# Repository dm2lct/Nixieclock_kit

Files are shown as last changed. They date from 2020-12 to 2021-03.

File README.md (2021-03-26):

Better version of my nixie clock. 
=====

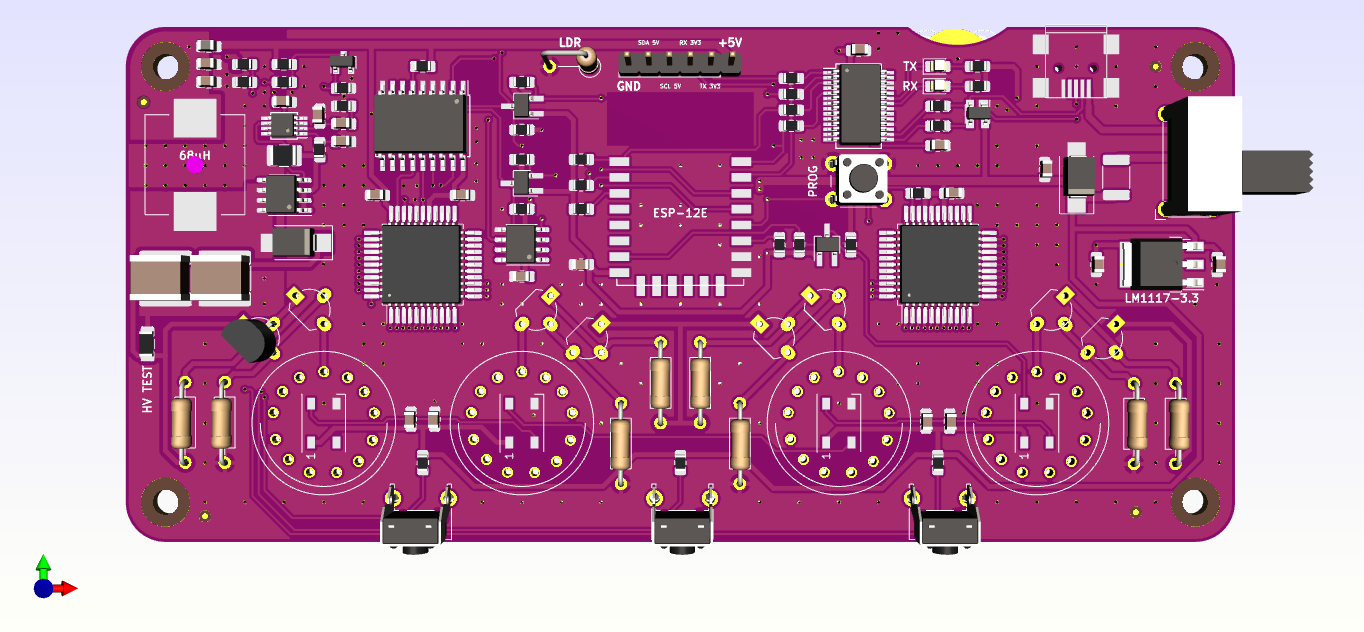
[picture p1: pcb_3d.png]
PCB 3D view Title


Feel free to build your own nixie clock from it.

The firmware can be found at https://codeberg.org/paul/nixie_clock

The documentation and assembly instructions are on https://wiki.turmlabor.de/index.php?title=Nixie_Uhr_Bausatz_2.1 (currently only in german, sorry!)

Features:
  - IN14 nixie tubes but you can adapt many other nixie tubes, but some of them would not fit nicely in the board
  - ESP12e controller so you can make IoT with it and build your own botnet for world domination, if you have enough clocks.
    But mainly the wifi is used to get the time from a ntp-server and for controlling the clock with MQTT
  - DS3231 RTC for everyone who does not like IoT and does also not want to be enslaved from AI
  - WS2812B under each nixie tube to make them look more fancy
  - runs from a simple USB charger, although it uses a mini-usb B socket, which is better to solder, so you need a mini-usb cable
  - you can program the controller with your Arduino IDE over USB
  - optimized nixie power supply. Now the entire clock ownly draws about 450mA from the power supply
  - cleaned up the schematic a little: Simpler protection circuit

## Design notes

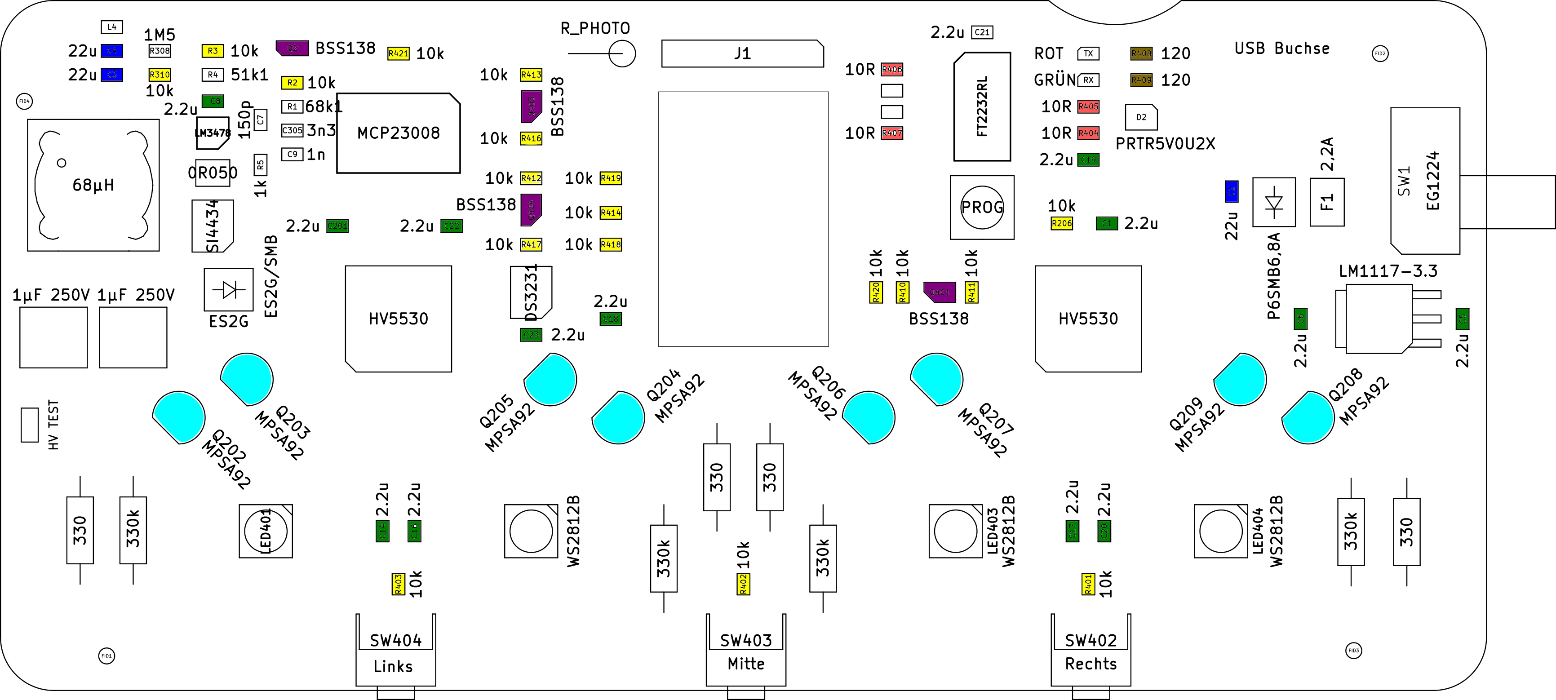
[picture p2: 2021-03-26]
Gerber/Nixie_proj-F.Fab.svg.png

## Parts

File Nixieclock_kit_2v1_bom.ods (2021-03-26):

BOM
Item | Qty | Reference(s) | Value | Reichelt | manf#
1 | 1 | 68uH1 | INDUCTOR | WUE 7447709680 | 7447709680
2 | 1 | BT401 | Battery_Cell |  | BAT-HLD-012-SMT
3 | 14 | C1, C5, C6, C8, C14, C16, C17, C18, C19, C20, C21, C22, C23, C201 | 2.2u | KEM X5R0805 2,2U | C0805C225K8PACTU
4 | 3 | C2, C3, C4 | 22u | X5R-G0805 22/6 | GRM21BR60J226ME39L
5 | 1 | C7 | 150p | KEM C0G0805 150P | C0805C151J5GACTU
6 | 1 | C9 | 1n | KEM C0G0805 150P | C0805C151J5GACTU
7 | 2 | C12, C13 | 1u |  | 2225PC105MAT1A
8 | 1 | C305 | 3n3 | KEM X7R0805 3,3N | C0805C151J5GACTU
9 | 1 | D1 | P6SMB6,8A | P6SMB 6,8A SMD | P6SMB6,8A
10 | 1 | D2 | PRTR5V0U2X |  | PRTR5V0U2X,215
11 | 1 | D304 | ES2G/SMB | ES 2G SMD | ES2G-E3/52T
12 | 1 | D401 | TX | SMD-LED 0805 RT | KP-2012ID
13 | 1 | D402 | RX | SMD-LED 0805 GN | KP-2012SGD
14 | 1 | F1 | 2,2A | LITT MINISMDC110 | MINISMDC110F/24-2
15 | 4 | FID1, FID2, FID3, FID4 | Fiducial | n.b. | n.b.
16 | 4 | H1, H2, H3, H4 | MountingHole | n.b. | n.b.
17 | 1 | J1 | Conn_01x06_Male | n.b. | n.b.
18 | 1 | L4 | Ferrite_Bead | BLM21PG 331 | BLM21PG331 SN1D
19 | 4 | LED401, LED402, LED403, LED404 | WS2812B
20 | 1 | NT1 | Net-Tie_2 | n.b. | n.b.
21 | 1 | P301 | USB_OTG | USB BWM SMD | USB BWM SMD
22 | 1 | Q1 | SI4434 | SI4434DY-GE3 | SI4434DY-T1-GE3
23 | 1 | Q2 | BSS138 | BSS 138 SMD | BSS 138 SMD
24 | 8 | Q202, Q203, Q204, Q205, Q206, Q207, Q208, Q209 | MPSA92 | MPSA 92 | MPSA92
25 | 3 | Q401, Q403, Q404 | BSS138 | BSS 138 SMD | BSS 138 SMD
26 | 1 | R1 | 68k1 | RND 0805 1 68K | RND1550805S8F6802T5E
27 | 18 | R2, R3, R206, R310, R401, R402, R403, R410, R411, R412, R413, R414, R416, R417, R418, R419, R420, R421 | 10k | RND 0805 1 10K | RND1550805S8F1002T5E
28 | 1 | R4 | 51k1 | RND 0805 1 51K | RND1550805S8F5102T5E
29 | 1 | R5 | 1k | RND 0805 1 51K | RND1550805S8F5102T5E
30 | 4 | R201, R203, R205, R208 | 330k | VI MBB02070C3303 | MBB02070C3303FCT00
31 | 4 | R202, R204, R207, R209 | 330 | VI MBB02070C3300 | MBB02070C3300FCT00
32 | 1 | R308 | 1M5 | SMD-0805 1,50M | RC0805FR-071M5L
33 | 4 | R404, R405, R406, R407 | 10R | RND 0805 1 10 | RND1550805S8F100JT5E
34 | 2 | R408, R409 | 120 | RND 0805 1 120 | RND1550805S8F1200T5E
35 | 1 | R415 | R_PHOTO | n.b. | n.b.
36 | 1 | RSENSE301 | 0R050 | PAN ERJ8CWFR050 | ERJ-L14KF50MU
37 | 1 | SW1 | EG1224 |  | EG1224
38 | 1 | SW401 | SW_Push | RND 210-00192 | RND 210-00192
39 | 1 | SW402 | Rechts | RND 210-00258 | RND 210-00258
40 | 1 | SW403 | Mitte | RND 210-00258 | RND 210-00258
41 | 1 | SW404 | Links | RND 210-00258 | RND 210-00258
42 | 4 | TBE201, TBE202, TBE203, TBE204 | IN14
43 | 1 | U1 | DS3231MZ |  | DS3231MZ+
44 | 1 | U2 | LM1117-3.3 | LM 1117 IDT-3.3 | LM1117IDT-3.3/NOPB
45 | 1 | U3 | LM3478 | LM 3478 MM | LM3478MM/NOPB
46 | 2 | U201, U202 | HV5530 bzw HV5522 |  | HV5522PG-G
47 | 1 | U401 | ESP-12E | DEBO ESP8266-12F | ESP-12S
48 | 1 | U402 | FT232RL | FT 232 RL | FT232RL-REEL
49 | 1 | U403 | MCP23008 |  | MCP23008-E/SO
50 | 2 | W401, W402 | TEST_2P | n.b. | n.b.

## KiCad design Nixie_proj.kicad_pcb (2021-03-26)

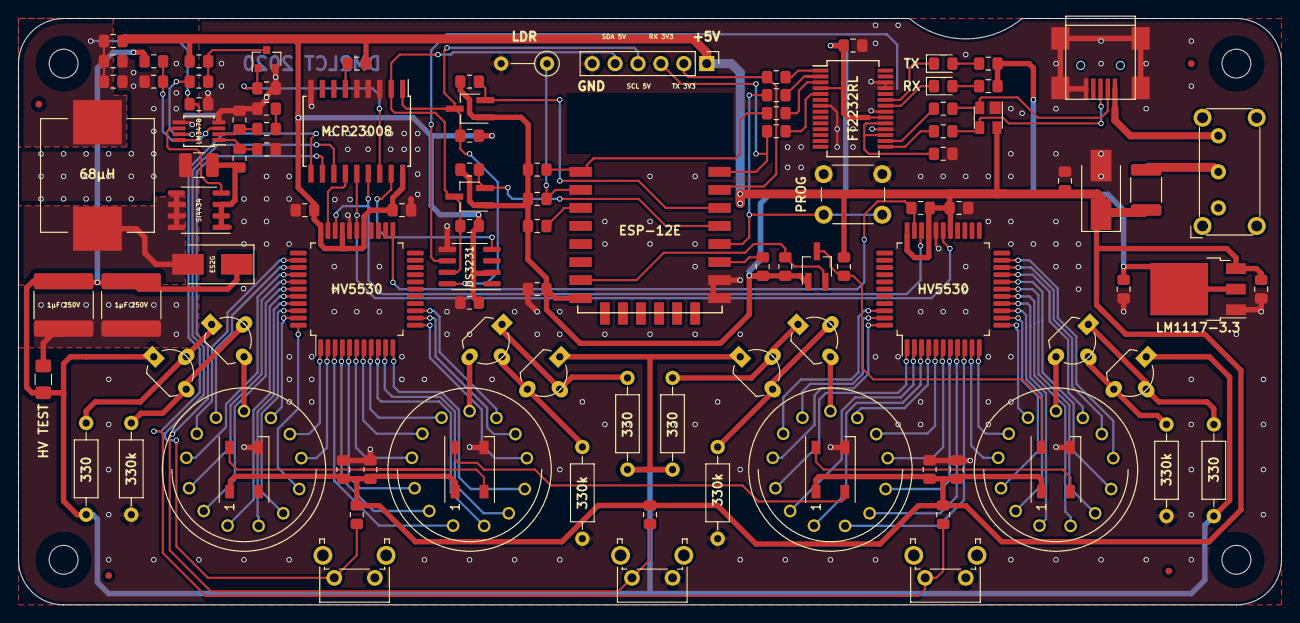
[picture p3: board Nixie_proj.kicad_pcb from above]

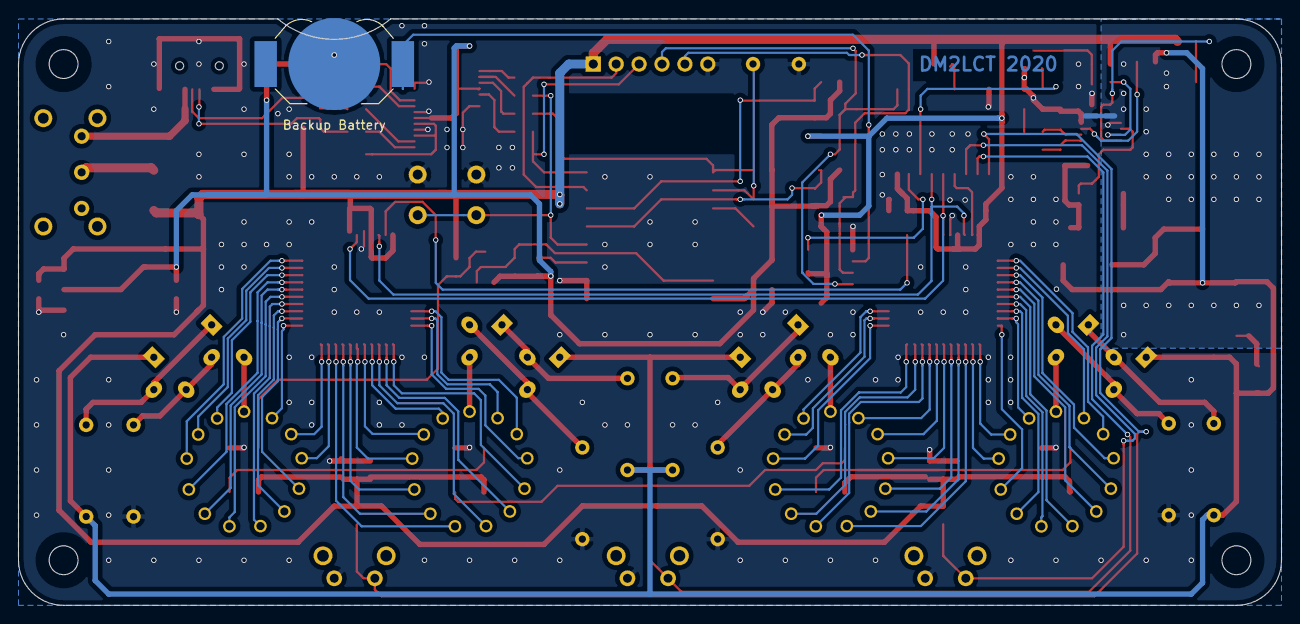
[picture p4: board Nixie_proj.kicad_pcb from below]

Board: 2 copper layers, 140.0 x 65.0 mm, 117 parts (2 on the bottom side), 117 nets.

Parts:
1µF 250V, 1µF 250V#2: 1u; C_2225_5664Metric_Pad1.80x6.60mm_HandSolder
68µH: INDUCTOR; L_Wuerth_WE-PD-Typ-LS_Handsoldering
330, 330#2, 330#3, 330#4: 330; R_Axial_DIN0207_L6.3mm_D2.5mm_P10.16mm_Horizontal
330k, 330k#2, 330k#3, 330k#4: 330k; R_Axial_DIN0207_L6.3mm_D2.5mm_P10.16mm_Horizontal
Backup Battery: Battery_Cell; BatteryHolder_LINX_BAT-HLD-012-SMT
C1, C5, C6, C8, C14, C16, C17, C18, C19, C20, C21, C22, C23, C201: 2.2u; C_0805_2012Metric_Pad1.15x1.40mm_HandSolder
C2, C3, C4: 22u; C_0805_2012Metric_Pad1.15x1.40mm_HandSolder
C7: 150p; C_0805_2012Metric_Pad1.15x1.40mm_HandSolder
C9: 1n; C_0805_2012Metric_Pad1.15x1.40mm_HandSolder
C305: 3n3; C_0805_2012Metric_Pad1.15x1.40mm_HandSolder
D1: P6SMB6,8A; D_SMB_Handsoldering
D2: PRTR5V0U2X; SOT-143
DS3231: DS3231MZ; SOIC-8_3.9x4.9mm_P1.27mm
ES2G: ES2G/SMB; D_SMB_Handsoldering
ESP-12E: ESP-12E; ESP-12E_SMD
F1: 2,2A; Fuse_1812_4532Metric_Pad1.30x3.40mm_HandSolder
FID1, FID2, FID3, FID4: Fiducial; Fiducial_0.75mm_Mask1.5mm
FT2232RL: FT232RL; SSOP-28_5.3x10.2mm_P0.65mm
H1, H2, H3: MountingHole; MountingHole_3.2mm_M3_DIN965
H4: eMountingHole; MountingHole_3.2mm_M3_DIN965
HV5530, HV5530#2: HV5530; MQFP-44_10x10mm_P0.8mm
HV TEST: TEST; R_1206_3216Metric_Pad1.42x1.75mm_HandSolder
J1: Conn_01x06_Male; PinHeader_1x06_P2.54mm_Vertical
L4: Ferrite_Bead; L_0805_2012Metric_Pad1.15x1.40mm_HandSolder
LDR: R_PHOTO; R_Axial_DIN0207_L6.3mm_D2.5mm_P5.08mm_Vertical
LED401, LED402, LED403, LED404: WS2812B; LED_WS2812B_PLCC4_5.0x5.0mm_P3.2mm
LM1117-3.3: LM1117-3.3; TO-252-3_TabPin2
LM3478: LM3478; MSOP-8_3x3mm_P0.65mm
MCP23008: MCP23008; SOIC-18W_7.5x11.6mm_P1.27mm
NT1: Net-Tie_2; NetTie-2_SMD_Pad0.5mm
P301: USB Buchse; USB_Mini-B
PROG: SW_Push; SW_PUSH_6mm_H4.3mm
Q2: BSS138; SOT-23
Q202, Q203, Q204, Q205, Q206, Q207, Q208, Q209: MPSA92; TO-92_Molded_Wide_Oval
Q401, Q403, Q404: BSS138; SOT-23W_Handsoldering
R1: 68k1; R_0805_2012Metric_Pad1.15x1.40mm_HandSolder
R2, R3, R206, R310, R401, R402, R403, R410, R411, R412, R413, R414, R416, R417, R418, R419, R420, R421: 10k; R_0805_2012Metric_Pad1.15x1.40mm_HandSolder
R4: 51k1; R_0805_2012Metric_Pad1.15x1.40mm_HandSolder
R5: 1k; R_0805_2012Metric_Pad1.15x1.40mm_HandSolder
R308: 1M5; R_0805_2012Metric_Pad1.15x1.40mm_HandSolder
R404, R405, R406, R407: 10R; R_0805_2012Metric_Pad1.15x1.40mm_HandSolder
R408, R409: 120; R_0805_2012Metric_Pad1.15x1.40mm_HandSolder
RSENSE301: 0R050; R_1210_3225Metric_Pad1.42x2.65mm_HandSolder
RX: GRÜN; LED_0805_2012Metric_Pad1.15x1.40mm_HandSolder
SI4434: SI4434; SOIC-8_3.9x4.9mm_P1.27mm
SW1: EG1224; SW_E-Switch_EG1224_SPDT_Angled
SW402: Rechts; SW_Tactile_SPST_Angled_PTS645Vx39-2LFS
SW403: Mitte; SW_Tactile_SPST_Angled_PTS645Vx39-2LFS
SW404: Links; SW_Tactile_SPST_Angled_PTS645Vx39-2LFS
TBE201, TBE202, TBE203, TBE204: IN14; IN-14-mod
TX: ROT; LED_0805_2012Metric_Pad1.15x1.40mm_HandSolder
W401, W402: TEST_2P; R_0805_2012Metric_Pad1.15x1.40mm_HandSolder

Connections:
+3V3: C6.1, C18.1, C21.2, ESP-12E.8, FT2232RL.4, FT2232RL.20, LM1117-3.3.2, Q401.1, Q403.1, Q404.1, R408.1, R409.1, R410.1, R412.1, R413.1, R414.1, R418.1, R419.1, R420.1
+5V: C1.1, C2.1, C5.1, C14.1, C16.1, C17.1, C20.1, C22.1, C23.2, C201.1, D1.1, D2.4, DS3231.2, F1.1, HV5530.27, HV5530.30, HV5530.33, HV5530#2.27, HV5530#2.30, HV5530#2.33, J1.1, L4.2, LED401.1, LED402.1, LED403.1, LED404.1, LM1117-3.3.3, MCP23008.18, R3.2, R206.1, R401.2, R402.2, R403.2, R411.1, R416.1, R417.1, R421.1
/Microcontroller and clock/BTN1: MCP23008.10, R401.1, SW402.2
/Microcontroller and clock/BTN2: MCP23008.11, R402.1, SW403.2
/Microcontroller and clock/BTN3: MCP23008.12, R403.1, SW404.2
/Microcontroller and clock/HVCLOCK: HV5530.28, HV5530#2.28, MCP23008.14
/Microcontroller and clock/HVDATA: HV5530.32, MCP23008.13
/Microcontroller and clock/HVSTROBE: HV5530.31, HV5530#2.31, MCP23008.15
/Microcontroller and clock/HV_SHDN: MCP23008.16, Q2.1, R2.2
/Microcontroller and clock/RX: ESP-12E.16, J1.3, R407.1
/Microcontroller and clock/SCL_3V3: ESP-12E.14, Q403.2, R413.2
/Microcontroller and clock/SCL_5V: DS3231.8, J1.4, MCP23008.1, Q403.3, R416.2
/Microcontroller and clock/SDA_3V3: ESP-12E.13, Q404.2, R412.2
/Microcontroller and clock/SDA_5V: DS3231.7, J1.5, MCP23008.2, Q404.3, R417.2
/Microcontroller and clock/TX: ESP-12E.15, J1.2, R406.1
/Microcontroller and clock/USBD+: D2.3, P301.3, R404.2
/Microcontroller and clock/USBD-: D2.2, P301.2, R405.2
/Power Supply/Boost_Drain: 68µH.2, ES2G.2, SI4434.5, SI4434.6, SI4434.7, SI4434.8
/Power Supply/Boost_ZK: 68µH.1, C3.1, C4.1, C8.2, L4.1, LM3478.8
/Power Supply/FB: LM3478.3, R308.2, R310.1
/Power Supply/Isen: C9.2, LM3478.1, R5.2
/Power Supply/PWRGND: 1µF 250V.2, 1µF 250V#2.2, C3.2, C4.2, HV TEST.2, LM3478.5, NT1.1, R310.2, RSENSE301.2
/Tubes with drivers/A0: HV5530.2, TBE201.11
/Tubes with drivers/A1: HV5530.35, TBE201.3
/Tubes with drivers/A2: HV5530.37, TBE201.4
/Tubes with drivers/A3: HV5530.38, TBE201.5
/Tubes with drivers/A4: HV5530.39, TBE201.6
/Tubes with drivers/A5: HV5530.40, TBE201.7
/Tubes with drivers/A6: HV5530.41, TBE201.8
/Tubes with drivers/A7: HV5530.42, TBE201.9
/Tubes with drivers/A8: HV5530.44, TBE201.10
/Tubes with drivers/A9: HV5530.1, TBE201.12
/Tubes with drivers/AC1: HV5530.36, TBE201.2
/Tubes with drivers/AC2: HV5530.43, TBE201.13
/Tubes with drivers/B0: HV5530.13, TBE202.12
/Tubes with drivers/B1: HV5530.5, TBE202.5
/Tubes with drivers/B2: HV5530.6, TBE202.4
/Tubes with drivers/B3: HV5530.7, TBE202.3
/Tubes with drivers/B4: HV5530.4, TBE202.6
/Tubes with drivers/B5: HV5530.3, TBE202.7
/Tubes with drivers/B6: HV5530.9, TBE202.8
/Tubes with drivers/B7: HV5530.10, TBE202.9
/Tubes with drivers/B8: HV5530.11, TBE202.10
/Tubes with drivers/B9: HV5530.12, TBE202.11
/Tubes with drivers/BC1: HV5530.8, TBE202.2
/Tubes with drivers/BC2: HV5530.14, TBE202.13
/Tubes with drivers/C0: HV5530#2.9, TBE203.8
/Tubes with drivers/C1: HV5530#2.42, TBE203.3
/Tubes with drivers/C2: HV5530#2.44, TBE203.4
/Tubes with drivers/C3: HV5530#2.1, TBE203.5
/Tubes with drivers/C4: HV5530#2.2, TBE203.6
/Tubes with drivers/C5: HV5530#2.3, TBE203.7
/Tubes with drivers/C6: HV5530#2.5, TBE203.12
/Tubes with drivers/C7: HV5530#2.6, TBE203.11
/Tubes with drivers/C8: HV5530#2.7, TBE203.10
/Tubes with drivers/C9: HV5530#2.8, TBE203.9
/Tubes with drivers/CC1: HV5530#2.43, TBE203.2
/Tubes with drivers/CC2: HV5530#2.4, TBE203.13
/Tubes with drivers/D0: HV5530#2.20, TBE204.12
/Tubes with drivers/D1: HV5530#2.11, TBE204.3
/Tubes with drivers/D2: HV5530#2.10, TBE204.4
/Tubes with drivers/D3: HV5530#2.13, TBE204.5
/Tubes with drivers/D4: HV5530#2.14, TBE204.6
/Tubes with drivers/D5: HV5530#2.15, TBE204.7
/Tubes with drivers/D6: HV5530#2.16, TBE204.8
/Tubes with drivers/D7: HV5530#2.17, TBE204.9
/Tubes with drivers/D8: HV5530#2.18, TBE204.10
/Tubes with drivers/D9: HV5530#2.21, TBE204.11
/Tubes with drivers/DC1: HV5530#2.12, TBE204.2
/Tubes with drivers/DC2: HV5530#2.19, TBE204.13
GND: 330k.2, 330k#2.2, 330k#3.2, 330k#4.2, Backup Battery.2, C1.2, C2.2, C5.2, C6.2, C7.2, C8.1, C9.1, C14.2, C16.2, C17.2, C18.2, C19.2, C20.2, C21.1, C22.2, C23.1, C201.2, D1.2, D2.1, DS3231.5, ESP-12E.9, ESP-12E.10, FT2232RL.7, FT2232RL.18, FT2232RL.21, FT2232RL.25, FT2232RL.26, HV5530.29, HV5530#2.29, J1.6, LDR.2, LED401.3, LED402.3, LED403.3, LED404.3, LM1117-3.3.1, LM3478.4, MCP23008.3, MCP23008.4, MCP23008.5, MCP23008.9, NT1.2, P301.5, P301.6, PROG.2, Q2.2, R1.2, R2.1, SW402.1, SW403.1, SW404.1
unnamed: Backup Battery.1, DS3231.6
unnamed: C19.1, FT2232RL.17, FT2232RL.19
unnamed: C7.1, C305.1, LM3478.2
unnamed: C305.2, R1.1
unnamed: FT2232RL.23, TX.1
unnamed: R408.2, TX.2
unnamed: FT2232RL.22, RX.1
unnamed: R409.2, RX.2
unnamed: F1.2, SW1.2
unnamed: LED401.4, LED402.2
unnamed: LED402.4, LED403.2
unnamed: LED403.4, LED404.2
unnamed: LED404.4, Q401.3, R411.2
unnamed: P301.1, SW1.3
unnamed: R5.1, RSENSE301.1, SI4434.1, SI4434.2, SI4434.3
unnamed: LM3478.6, SI4434.4
unnamed: Q2.3, R3.1, R4.2
unnamed: 330.2, Q202.2, Q203.1
unnamed: 330k.1, Q202.3, Q203.2
unnamed: Q203.3, TBE201.1
unnamed: 330#2.2, Q204.2, Q205.1
unnamed: 330k#2.1, Q204.3, Q205.2
unnamed: Q205.3, TBE202.1
unnamed: 330#3.2, Q206.2, Q207.1
unnamed: 330k#3.1, Q206.3, Q207.2
unnamed: Q207.3, TBE203.1
unnamed: 330#4.2, Q208.2, Q209.1
unnamed: 330k#4.1, Q208.3, Q209.2
unnamed: Q209.3, TBE204.1
unnamed: ESP-12E.7, Q401.2, R410.2
unnamed: LM3478.7, R4.1
unnamed: HV5530.23, HV5530#2.32, R206.2
unnamed: FT2232RL.15, R404.1
unnamed: FT2232RL.16, R405.1
unnamed: FT2232RL.1, R406.2
unnamed: FT2232RL.5, R407.2
unnamed: ESP-12E.2, LDR.1, R414.2
unnamed: ESP-12E.3, R418.2
unnamed: ESP-12E.1, R419.2, W401.2
unnamed: ESP-12E.11, R420.2
unnamed: MCP23008.6, R421.2
unnamed: ESP-12E.12, PROG.1, W402.2
unnamed: DS3231.4, MCP23008.17
unnamed: FT2232RL.2, W402.1
unnamed: FT2232RL.3, W401.1
VAA: 1µF 250V.1, 1µF 250V#2.1, 330.1, 330#2.1, 330#3.1, 330#4.1, ES2G.1, HV TEST.1, Q202.1, Q204.1, Q206.1, Q208.1, R308.1

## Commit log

2020-12-30 neues repo aufgemacht, das alte war kaputtgespielt...
    [Nixie_proj.kicad_pcb, Nixie_proj.sch, nixie_mcu.sch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]
2020-12-30 wenn man einmal anfängt...
    [Nixie_proj.kicad_pcb]
2021-01-19 Fertigungsdaten erstellt
    [Nixie_proj-B_Cu.gbl, Nixie_proj-B_Mask.gbs, Nixie_proj-B_SilkS.gbo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]
2021-03-26 bom hinzugefügt
    [Nixieclock_kit_2v1_bom.ods]
2021-03-26 mal wieder aktualisiert
    [Nixie_proj.kicad_pcb]
